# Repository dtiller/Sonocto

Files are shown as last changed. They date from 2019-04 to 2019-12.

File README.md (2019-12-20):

# Sonocto

This repo contains the MPLAB PIC code, Kicad board definition, and Arduino library and test suite for the Sonocto(tm) eight channel sonar module controller.

The author(s) assume/s no liability for your use of this code and no warranty, express or implied, exists.

The latest version is in the SonoctoPlus directory and uses a '1525 PIC. The code in the non-Plus directory is written for a '1523 PIC and may not have all of the features of the Plus version.

See the main.h and main.c files for details of the I2C protocol.

There are examples and test cases in the arduino area.

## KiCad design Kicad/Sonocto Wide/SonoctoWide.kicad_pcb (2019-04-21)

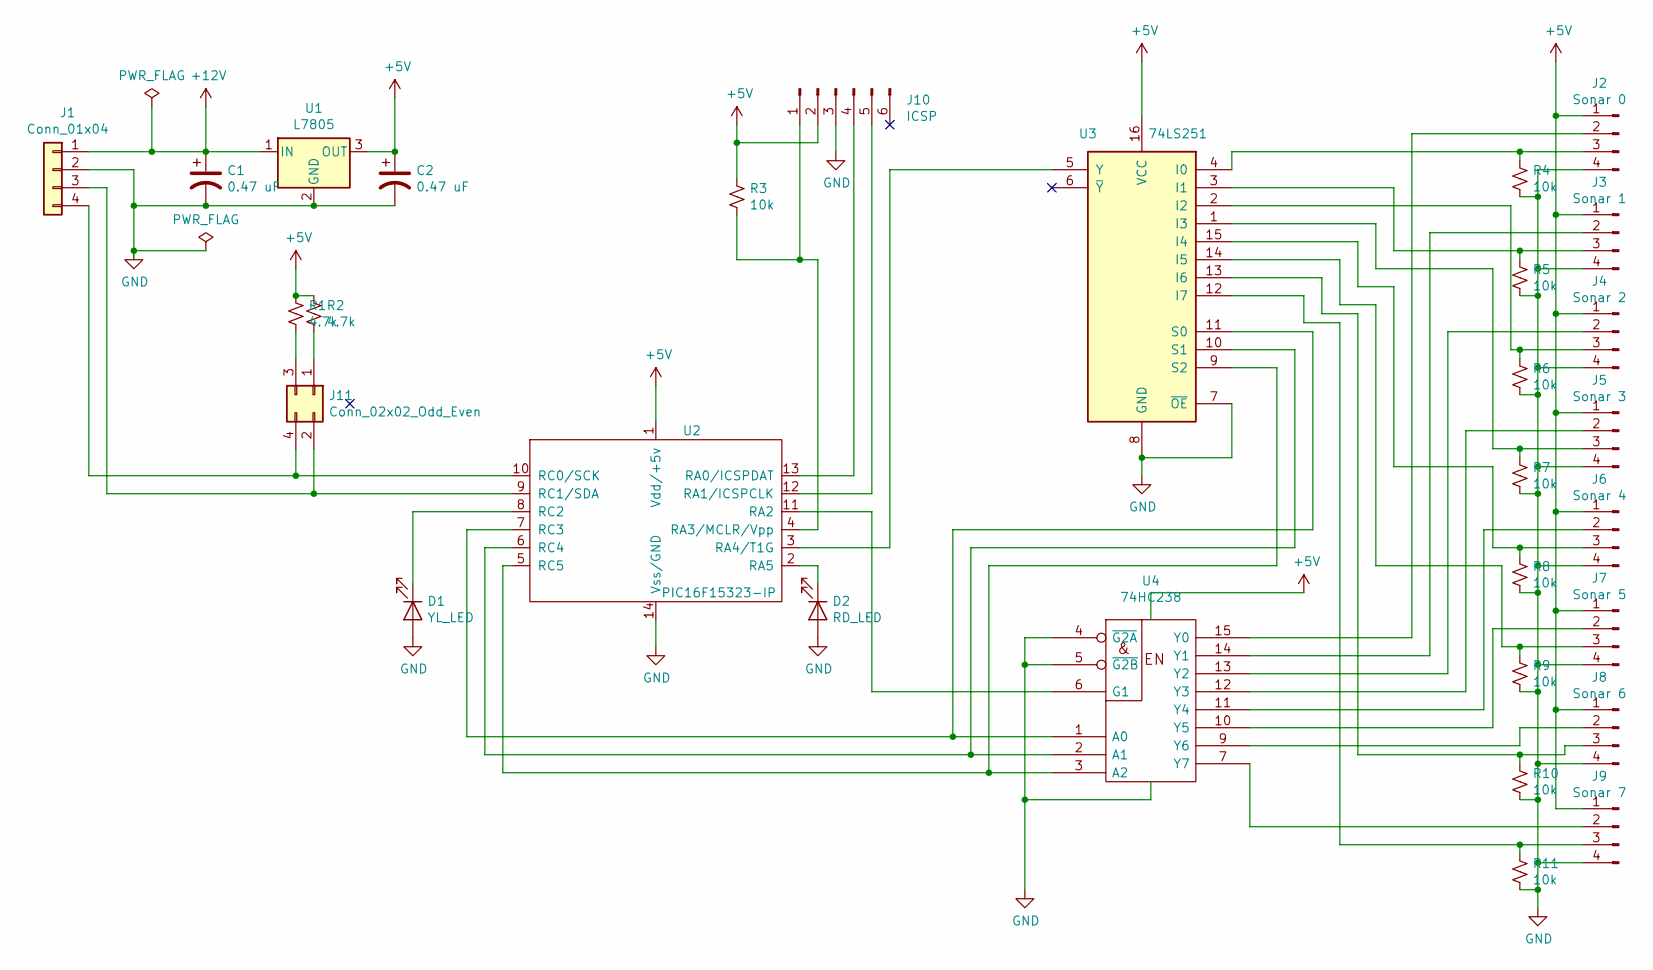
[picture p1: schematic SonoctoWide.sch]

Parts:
C1, C2: 0.47 uF; CP_Radial_D5.0mm_P2.00mm
D1: YL_LED; LED_D3.0mm
D2: RD_LED; LED_D3.0mm
J1: Conn_01x04; PinHeader_1x04_P2.54mm_Vertical
J2: Sonar 0; PinHeader_1x04_P2.54mm_Vertical
J3: Sonar 1; PinHeader_1x04_P2.54mm_Vertical
J4: Sonar 2; PinHeader_1x04_P2.54mm_Vertical
J5: Sonar 3; PinHeader_1x04_P2.54mm_Vertical
J6: Sonar 4; PinHeader_1x04_P2.54mm_Vertical
J7: Sonar 5; PinHeader_1x04_P2.54mm_Vertical
J8: Sonar 6; PinHeader_1x04_P2.54mm_Vertical
J9: Sonar 7; PinHeader_1x04_P2.54mm_Vertical
J10: ICSP; PinHeader_1x06_P2.54mm_Vertical
J11: Conn_02x02_Odd_Even; PinHeader_2x02_P2.54mm_Vertical
R1, R2: 4.7k; R_Axial_DIN0204_L3.6mm_D1.6mm_P1.90mm_Vertical
R3, R4, R5, R6, R7, R8, R9, R10, R11: 10k; R_Axial_DIN0204_L3.6mm_D1.6mm_P1.90mm_Vertical
U1: L7805; TO-220-3_Vertical
U2: PIC16F15323-IP; DIP-14_W7.62mm
U3: 74LS251; DIP-16_W7.62mm
U4: 74HC238; DIP-16_W7.62mm

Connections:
+5V: C2.1, J2.1, J3.1, J4.1, J5.1, J6.1, J7.1, J8.1, J9.1, J10.2, R1.1, R2.1, R3.1, U1.3 (OUT), U2.1 (Vdd/+5v), U3.16 (VCC), U4.16 (VCC)
+12V: C1.1, J1.1, U1.1 (IN)
GND: C1.2, C2.2, D1.2 (A), D2.2 (A), J1.2, J2.4, J3.4, J4.4, J5.4, J6.4, J7.4, J8.4, J9.4, J10.3, R4.2, R5.2, R6.2, R7.2, R8.2, R9.2, R10.2, R11.2, U1.2 (GND), U2.14 (Vss/GND), U3.7 (~OE), U3.8 (GND), U4.4 (~G2A), U4.5 (~G2B), U4.8 (GND)
unnamed: D1.1 (K), U2.8 (RC2)
unnamed: D2.1 (K), U2.2 (RA5)
unnamed: J1.3, J11.2, U2.9 (RC1/SDA)
unnamed: J1.4, J11.4, U2.10 (RC0/SCK)
unnamed: J2.2, U4.15 (Y0)
unnamed: J2.3, R4.1, U3.4 (I0)
unnamed: J3.2, U4.14 (Y1)
unnamed: J3.3, R5.1, U3.3 (I1)
unnamed: J4.2, U4.13 (Y2)
unnamed: J4.3, R6.1, U3.2 (I2)
unnamed: J5.2, U4.12 (Y3)
unnamed: J5.3, R7.1, U3.1 (I3)
unnamed: J6.2, U4.11 (Y4)
unnamed: J6.3, R8.1, U3.15 (I4)
unnamed: J7.2, U4.10 (Y5)
unnamed: J7.3, R9.1, U3.14 (I5)
unnamed: J8.2, U4.9 (Y6)
unnamed: J8.3, R10.1, U3.13 (I6)
unnamed: J9.2, U4.7 (Y7)
unnamed: J9.3, R11.1, U3.12 (I7)
unnamed: J10.1, R3.2, U2.4 (RA3/MCLR/Vpp)
unnamed: J10.4, U2.13 (RA0/ICSPDAT)
unnamed: J10.5, U2.12 (RA1/ICSPCLK)
unnamed: J11.1, R2.2
unnamed: J11.3, R1.2
unnamed: U2.3 (RA4/T1G), U3.5 (Y)
unnamed: U2.5 (RC5), U3.9 (S2), U4.3 (A2)
unnamed: U2.6 (RC4), U3.10 (S1), U4.2 (A1)
unnamed: U2.7 (RC3), U3.11 (S0), U4.1 (A0)
unnamed: U2.11 (RA2), U4.6 (G1)

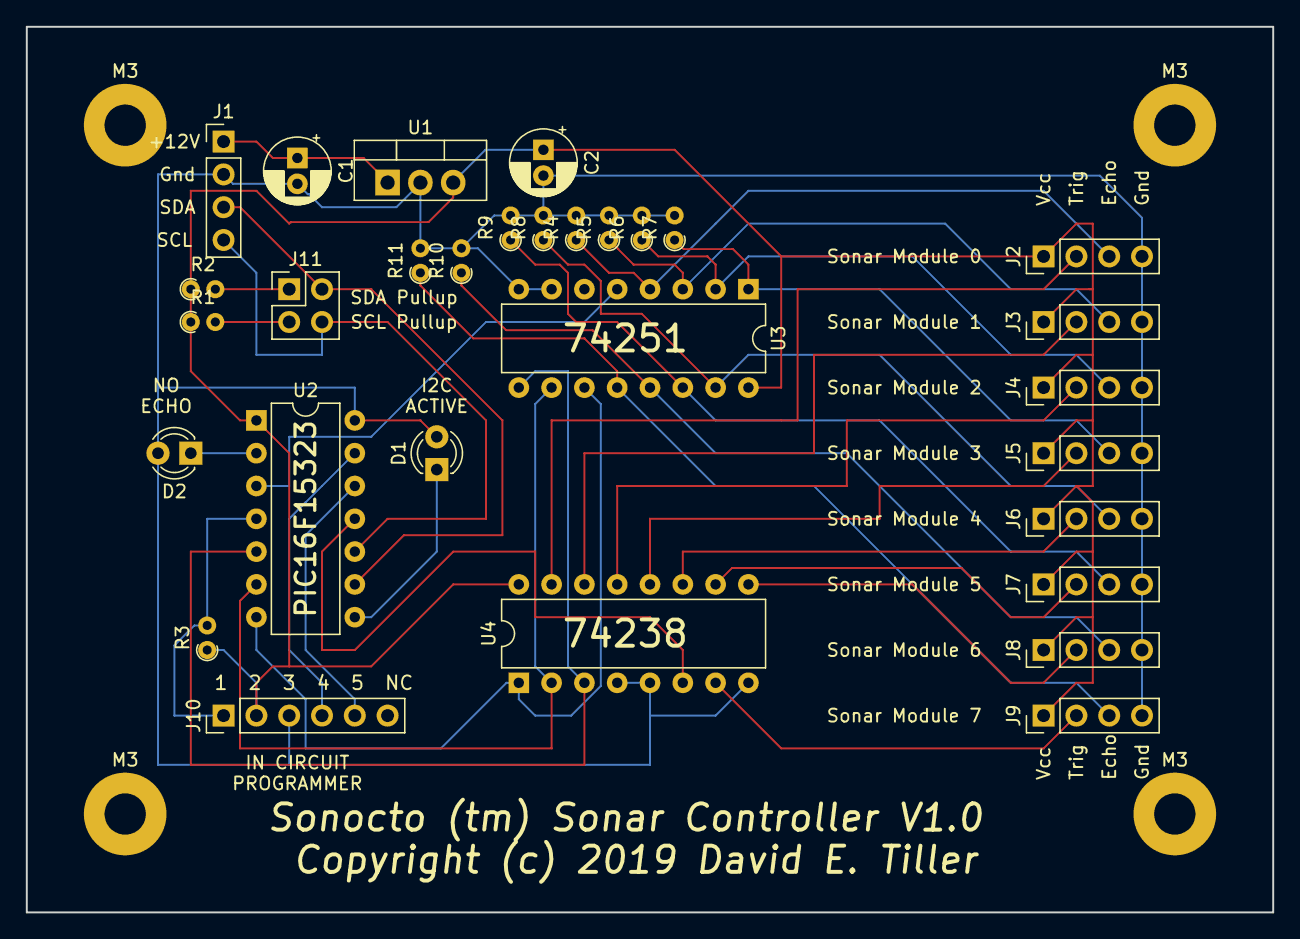
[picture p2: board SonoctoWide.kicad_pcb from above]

Board: 2 copper layers, 96.5 x 68.6 mm, 34 parts (0 on the bottom side), 33 nets.

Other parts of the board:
M3, M3#2, M3#3, M3#4: MountingHole_3.2mm_M3_Pad

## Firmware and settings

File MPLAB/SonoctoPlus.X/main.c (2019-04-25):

/**
  Generated Main Source File

  Company:
    Microchip Technology Inc.

  File Name:
    main.c

  Summary:
    This is the main file generated using PIC10 / PIC12 / PIC16 / PIC18 MCUs

  Description:
    This header file provides implementations for driver APIs for all modules selected in the GUI.
    Generation Information :
        Product Revision  :  PIC10 / PIC12 / PIC16 / PIC18 MCUs - 1.76
        Device            :  PIC16F15325
        Driver Version    :  2.00
*/

/*
    (c) 2018 Microchip Technology Inc. and its subsidiaries. 
    
    Subject to your compliance with these terms, you may use Microchip software and any 
    derivatives exclusively with Microchip products. It is your responsibility to comply with third party 
    license terms applicable to your use of third party software (including open source software) that 
    may accompany Microchip software.
    
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
    IN NO EVENT WILL MICROCHIP BE LIABLE FOR ANY INDIRECT, SPECIAL, PUNITIVE, 
    INCIDENTAL OR CONSEQUENTIAL LOSS, DAMAGE, COST OR EXPENSE OF ANY KIND 
    WHATSOEVER RELATED TO THE SOFTWARE, HOWEVER CAUSED, EVEN IF MICROCHIP 
    HAS BEEN ADVISED OF THE POSSIBILITY OR THE DAMAGES ARE FORESEEABLE. TO 
    THE FULLEST EXTENT ALLOWED BY LAW, MICROCHIP'S TOTAL LIABILITY ON ALL 
    CLAIMS IN ANY WAY RELATED TO THIS SOFTWARE WILL NOT EXCEED THE AMOUNT 
    OF FEES, IF ANY, THAT YOU HAVE PAID DIRECTLY TO MICROCHIP FOR THIS 
    SOFTWARE.
*/

#include "mcc_generated_files/mcc.h"
#include "mcc_generated_files/drivers/i2c_slave.h"

#include "main.h"

volatile uint16_t timerValue = 0;
volatile uint8_t count = 0;
volatile uint8_t waitForGate[8] = {0, 0, 0, 0, 0, 0, 0, 0};

volatile uint16_t maxReading[8] = {0, 0, 0, 0, 0, 0, 0, 0};
volatile uint16_t minReading[8] = {0xffff, 0xffff, 0xffff, 0xffff, 0xffff, 0xffff, 0xffff, 0xffff};

const uint16_t SAF_ADDR = END_FLASH - CONFIG_SIZE;

config_t config;

void initializeConfig(config_t *cfg) {
    cfg->cfg.i2cAddr = I2C_UPPER_BITS;
    cfg->cfg.enabled = 0xff;
    for (uint8_t i = 0; i < 8; i++) {
        cfg->cfg.maxEchoLimit[i] = 0x0f;
    }
}

uint8_t writeNVRAM(config_t *cfg) {
    return FLASH_WriteBlock(SAF_ADDR, cfg->dummy);
}

void readNVRAM(void) {
    uint16_t temp = FLASH_ReadWord(SAF_ADDR);
    if ((temp & 0x3f00) != 0) {
        // NVRAM not initialized - let's write the defaults in.
        writeNVRAM(&config);
    } else {
        for (uint8_t i = 0; i < WRITE_FLASH_BLOCKSIZE; i++) {
            config.dummy[i] = FLASH_ReadWord(SAF_ADDR + i);
        }
    }
}

// Read from the perspective of the SLAVE
void mySlaveReadHandler(void) {
    count = 0;
    LED_READ_SetHigh();
    
    uint8_t dataByte = i2c1_driver_getRXData();
    uint8_t channel = (dataByte & 0x07);
    uint8_t command;
    if (dataByte & 0x80) {
        command = CMD_ECHO_LIM_WRITE;
    } else if ((dataByte & 0xf0) == 0) {
        // 5 bit command + channel
        command = (dataByte >> 3) & 0x01;
    } else if ((dataByte & 0xf0) == 0x10) {
        command = ((dataByte >> 2) & 0x03) + 2;
    } else {
        command = ((dataByte >> 5) & 0x03) + 5;
    }
    
    switch (command) {
        case CMD_READ_DISTANCE:
            readDistance(channel);
            break;
        case CMD_READ_ECHOLIMIT:
            readEchoLimit(channel, dataByte);
            break;
        case CMD_MIN_MAX:
            readResetMinMaxStats(channel, dataByte);
            break;
        case CMD_ENABLE:
            enableDisable(channel, dataByte);
            break;
        case CMD_CONFIG:
            manageConfig(channel, dataByte);
            break;
        case CMD_ECHO_LIM_WRITE:
            setEchoLimit(channel, dataByte);
            break;
        case CMD_I2C_ADDR:
            setI2CAddr(channel, dataByte);
            break;
        case CMD_RESET:
            reboot(channel, dataByte);
            break;
        case CMD_VERSION:
            readVersion(channel, dataByte);
            break;
        case CMD_UNDEF_05:
        default:
            timerValue = UNKNOWN_CMD;
            break;          
    }
}

// [ 0 0 0 0 0 ] [ A A A ]
void readDistance(uint8_t channel) {
    // Set Up mux/demux
    //LATC = (LATC & 0xc7) | value;
    if ((config.cfg.enabled & (1 << channel)) == 0) {
        timerValue = CHANNEL_DISABLED;
        return;
    }
    
    LATCbits.LATC3 = channel & 0x01;
    LATCbits.LATC4 = (channel >> 1) & 0x01;
    LATCbits.LATC5 = (channel >> 2) & 0x01;
    
    if (waitForGate[channel]) {
        TMR0_WriteTimer(0x0000);
        TMR0_StartTimer();
        while (!TMR0_HasOverflowOccured() && TMR1_CheckGateValueStatus()) ;
        TMR0_StopTimer();
        if (TMR0_HasOverflowOccured()) {
            timerValue = GATE_TIMEOUT;
            PIR0bits.TMR0IF = 0;
            
            return;
        }
    }
    
    TMR1_WriteTimer(0x0000);
    TMR0_WriteTimer(0xFFFF - ((config.cfg.maxEchoLimit[channel] + 1) << 10) + 1);
    TMR0_StartTimer();
    TMR1_StartTimer();
    TMR1_StartSinglePulseAcquisition();
    
    TRIGGER_SetHigh();
    __delay_us(10);
    TRIGGER_SetLow();
    
    while (!TMR1_HasOverflowOccured() && !TMR0_HasOverflowOccured() &&
            T1GCONbits.GGO_nDONE == 1) ;
    
    TMR0_StopTimer();
    TMR1_StopTimer();
    
    waitForGate[channel] = 0;
    
    uint16_t t = TMR1_ReadTimer();
    if (TMR0_HasOverflowOccured()) {
        if (t == 0) {
            timerValue = NO_MODULE;
        } else {
            timerValue = NO_ECHO;
            waitForGate[channel] = 1;
            LED_OVFL_SetHigh();
        }
    } else if (TMR1_HasOverflowOccured()) {
        timerValue = TMR1_OVFL;
        waitForGate[channel] = 1;
        LED_OVFL_SetHigh();
    } else {
        timerValue = t;
        if (t > maxReading[channel]) maxReading[channel] = t;
        if (t < minReading[channel]) minReading[channel] = t;
        
        LED_OVFL_SetLow();
    }
    
    PIR0bits.TMR0IF = 0;
    PIR4bits.TMR1IF = 0;
}

// [ 0 0 0 0 1 ] [ A A A ]
void readEchoLimit(uint8_t channel, uint8_t dataByte) {
    timerValue = config.cfg.maxEchoLimit[channel];
}

// [ 0 0 1 ] [ 0 = min 1 = max ] [ = 0 read 1 = reset] [ A A A ]
void readResetMinMaxStats(uint8_t channel, uint8_t dataByte) {
    uint8_t max = dataByte & 0x10;
    if (dataByte & 0x08) {
        timerValue = 0;
        // RESET
        if (max) {
            maxReading[channel] = 0;
        } else {
            minReading[channel] = 0xffff;
        }
    } else {
        if (max) {
            timerValue = maxReading[channel];
        } else {
            timerValue = minReading[channel];
        }
    }
}

// [ 0 1 0 ] [ 0 = disable 1 = enable] [ 0 = read 1 = write ] [ A A A ]
void enableDisable(uint8_t channel, uint8_t dataByte) {
    // Always return the previous value
    timerValue = (config.cfg.enabled >> channel) & 0x01;
    if (dataByte & 0x08) {
        config.cfg.enabled &= ~(1 << channel);
        config.cfg.enabled |= ((dataByte >> 4) & 0x01) << channel;
    }
}

// [ 0 0 0 1 0 0 ] [ X Y ]
// X Y Action
// 0 0 Copy NVRAM --> current config
// 0 1 Set NVRAM config to default values
// 1 0 Set current config to default values
// 1 1 Copy current config to NVRAM
void manageConfig(uint8_t channel, uint8_t dataByte) {
    uint8_t action = dataByte & 0x03;
    timerValue = 0;
    switch (action) {
        case 0:
            readNVRAM();
            break;
        case 1:
        { config_t localConfig;
            initializeConfig(&localConfig);
            writeNVRAM(&localConfig);
            break;
        }
        case 2:
            initializeConfig(&config);
            break;
        case 3:
            writeNVRAM(&config);
            break;
    }
}

// [ 0 0 0 1 0 1 x x ]
// Reboot device
void reboot(uint8_t channel, uint8_t dataByte) {
    RESET();
}

// [ 0 0 0 1 1 0 x x ]
// Read Version
void readVersion(uint8_t channel, uint8_t dataByte) {
    timerValue = VERSION;
}

// [ 0 1 1 b4 b3 b2 b1 b0 ]
// Set I2C address to 0 1 b4 b3 b2 b1 b0 
void setI2CAddr(uint8_t channel, uint8_t dataByte) {
    timerValue = i2c1_driver_getAddr() >> 1;
    config.cfg.i2cAddr = I2C_UPPER_BITS | (dataByte & 0x1f);
    i2c1_driver_setAddr(config.cfg.i2cAddr << 1);
}

// [ 1 ] [ X X X X ] [ A A A ]
void setEchoLimit(uint8_t channel, uint8_t dataByte) {
    uint8_t limit = (dataByte >> 3) & 0x0f;
    timerValue = config.cfg.maxEchoLimit[channel];
    config.cfg.maxEchoLimit[channel] = limit;
}

// Write from the perspective of the SLAVE
void mySlaveWriteHandler(void) {
    //if (i2c1_driver_isNACK() == 1) return;
    if (i2c1_driver_isData() == 1 && i2c1_driver_isNACK() == 1) return;
    
    switch (count) {
        case 0:
            i2c1_driver_TXData((timerValue >> 8) & 0xff);
            count++;
            break;
        case 1:
            i2c1_driver_TXData(timerValue & 0xff);
            count++;
            LED_READ_SetLow();
            break;
        default:
            i2c1_driver_TXData(READ_INDEX_EXCEEDED);
            break;
    }       
}

void startupLights(void) {
    // Blink at the same time if WDT fired, alternately if not
    // Check for WDT reset
    
    LED_READ_SetLow();

    if (__timeout == 0) {
        LED_OVFL_SetLow();
    } else {
        LED_OVFL_SetHigh();
    }
    
    TMR0_WriteTimer(0x0000);
    TMR0_StartTimer();
    
    for (int i = 0; i < 10; i++) {
        while (!TMR0_HasOverflowOccured()) ;
        PIR0bits.TMR0IF = 0;
        LED_OVFL_Toggle();
        LED_READ_Toggle();
    }
    
    TMR0_StopTimer();
    LED_OVFL_SetLow();
    LED_READ_SetLow();
}

/*
                         Main application
 */
void main(void)
{   
    // initialize the device
    SYSTEM_Initialize();
    
    startupLights();
    
    initializeConfig(&config);
    
    readNVRAM();
    
    i2c_slave_open();
    i2c_slave_setWriteIntHandler(mySlaveWriteHandler);
    i2c_slave_setReadIntHandler(mySlaveReadHandler);
    i2c1_driver_setAddr(config.cfg.i2cAddr << 1);
    i2c1_driver_start();    // Sets SEN = 1
    mssp1_enableIRQ();      // Sets SSP1IE = 1
    
    // When using interrupts, you need to set the Global and Peripheral Interrupt Enable bits
    // Use the following macros to:
    // Enable the Global Interrupts
    INTERRUPT_GlobalInterruptEnable();

    // Enable the Peripheral Interrupts
    INTERRUPT_PeripheralInterruptEnable();

    // Disable the Global Interrupts
    //INTERRUPT_GlobalInterruptDisable();

    // Disable the Peripheral Interrupts
    //INTERRUPT_PeripheralInterruptDisable();
      
    while (1)
    {
        CLRWDT();
    }
}
/**
 End of File
*/

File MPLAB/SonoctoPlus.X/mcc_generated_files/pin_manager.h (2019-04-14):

/**
  @Generated Pin Manager Header File

  @Company:
    Microchip Technology Inc.

  @File Name:
    pin_manager.h

  @Summary:
    This is the Pin Manager file generated using PIC10 / PIC12 / PIC16 / PIC18 MCUs

  @Description
    This header file provides APIs for driver for .
    Generation Information :
        Product Revision  :  PIC10 / PIC12 / PIC16 / PIC18 MCUs - 1.76
        Device            :  PIC16F15325
        Driver Version    :  2.11
    The generated drivers are tested against the following:
        Compiler          :  XC8 2.00
        MPLAB 	          :  MPLAB X 5.10	
*/

/*
    (c) 2018 Microchip Technology Inc. and its subsidiaries. 
    
    Subject to your compliance with these terms, you may use Microchip software and any 
    derivatives exclusively with Microchip products. It is your responsibility to comply with third party 
    license terms applicable to your use of third party software (including open source software) that 
    may accompany Microchip software.
    
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
    IN NO EVENT WILL MICROCHIP BE LIABLE FOR ANY INDIRECT, SPECIAL, PUNITIVE, 
    INCIDENTAL OR CONSEQUENTIAL LOSS, DAMAGE, COST OR EXPENSE OF ANY KIND 
    WHATSOEVER RELATED TO THE SOFTWARE, HOWEVER CAUSED, EVEN IF MICROCHIP 
    HAS BEEN ADVISED OF THE POSSIBILITY OR THE DAMAGES ARE FORESEEABLE. TO 
    THE FULLEST EXTENT ALLOWED BY LAW, MICROCHIP'S TOTAL LIABILITY ON ALL 
    CLAIMS IN ANY WAY RELATED TO THIS SOFTWARE WILL NOT EXCEED THE AMOUNT 
    OF FEES, IF ANY, THAT YOU HAVE PAID DIRECTLY TO MICROCHIP FOR THIS 
    SOFTWARE.
*/

#ifndef PIN_MANAGER_H
#define PIN_MANAGER_H

/**
  Section: Included Files
*/

#include <xc.h>

#define INPUT   1
#define OUTPUT  0

#define HIGH    1
#define LOW     0

#define ANALOG      1
#define DIGITAL     0

#define PULL_UP_ENABLED      1
#define PULL_UP_DISABLED     0

// get/set TRIGGER aliases
#define TRIGGER_TRIS                 TRISAbits.TRISA2
#define TRIGGER_LAT                  LATAbits.LATA2
#define TRIGGER_PORT                 PORTAbits.RA2
#define TRIGGER_WPU                  WPUAbits.WPUA2
#define TRIGGER_OD                   ODCONAbits.ODCA2
#define TRIGGER_ANS                  ANSELAbits.ANSA2
#define TRIGGER_SetHigh()            do { LATAbits.LATA2 = 1; } while(0)
#define TRIGGER_SetLow()             do { LATAbits.LATA2 = 0; } while(0)
#define TRIGGER_Toggle()             do { LATAbits.LATA2 = ~LATAbits.LATA2; } while(0)
#define TRIGGER_GetValue()           PORTAbits.RA2
#define TRIGGER_SetDigitalInput()    do { TRISAbits.TRISA2 = 1; } while(0)
#define TRIGGER_SetDigitalOutput()   do { TRISAbits.TRISA2 = 0; } while(0)
#define TRIGGER_SetPullup()          do { WPUAbits.WPUA2 = 1; } while(0)
#define TRIGGER_ResetPullup()        do { WPUAbits.WPUA2 = 0; } while(0)
#define TRIGGER_SetPushPull()        do { ODCONAbits.ODCA2 = 0; } while(0)
#define TRIGGER_SetOpenDrain()       do { ODCONAbits.ODCA2 = 1; } while(0)
#define TRIGGER_SetAnalogMode()      do { ANSELAbits.ANSA2 = 1; } while(0)
#define TRIGGER_SetDigitalMode()     do { ANSELAbits.ANSA2 = 0; } while(0)

// get/set RA4 procedures
#define RA4_SetHigh()            do { LATAbits.LATA4 = 1; } while(0)
#define RA4_SetLow()             do { LATAbits.LATA4 = 0; } while(0)
#define RA4_Toggle()             do { LATAbits.LATA4 = ~LATAbits.LATA4; } while(0)
#define RA4_GetValue()              PORTAbits.RA4
#define RA4_SetDigitalInput()    do { TRISAbits.TRISA4 = 1; } while(0)
#define RA4_SetDigitalOutput()   do { TRISAbits.TRISA4 = 0; } while(0)
#define RA4_SetPullup()             do { WPUAbits.WPUA4 = 1; } while(0)
#define RA4_ResetPullup()           do { WPUAbits.WPUA4 = 0; } while(0)
#define RA4_SetAnalogMode()         do { ANSELAbits.ANSA4 = 1; } while(0)
#define RA4_SetDigitalMode()        do { ANSELAbits.ANSA4 = 0; } while(0)

// get/set LED_OVFL aliases
#define LED_OVFL_TRIS                 TRISAbits.TRISA5
#define LED_OVFL_LAT                  LATAbits.LATA5
#define LED_OVFL_PORT                 PORTAbits.RA5
#define LED_OVFL_WPU                  WPUAbits.WPUA5
#define LED_OVFL_OD                   ODCONAbits.ODCA5
#define LED_OVFL_ANS                  ANSELAbits.ANSA5
#define LED_OVFL_SetHigh()            do { LATAbits.LATA5 = 1; } while(0)
#define LED_OVFL_SetLow()             do { LATAbits.LATA5 = 0; } while(0)
#define LED_OVFL_Toggle()             do { LATAbits.LATA5 = ~LATAbits.LATA5; } while(0)
#define LED_OVFL_GetValue()           PORTAbits.RA5
#define LED_OVFL_SetDigitalInput()    do { TRISAbits.TRISA5 = 1; } while(0)
#define LED_OVFL_SetDigitalOutput()   do { TRISAbits.TRISA5 = 0; } while(0)
#define LED_OVFL_SetPullup()          do { WPUAbits.WPUA5 = 1; } while(0)
#define LED_OVFL_ResetPullup()        do { WPUAbits.WPUA5 = 0; } while(0)
#define LED_OVFL_SetPushPull()        do { ODCONAbits.ODCA5 = 0; } while(0)
#define LED_OVFL_SetOpenDrain()       do { ODCONAbits.ODCA5 = 1; } while(0)
#define LED_OVFL_SetAnalogMode()      do { ANSELAbits.ANSA5 = 1; } while(0)
#define LED_OVFL_SetDigitalMode()     do { ANSELAbits.ANSA5 = 0; } while(0)

// get/set SCL1 aliases
#define SCL1_TRIS                 TRISCbits.TRISC0
#define SCL1_LAT                  LATCbits.LATC0
#define SCL1_PORT                 PORTCbits.RC0
#define SCL1_WPU                  WPUCbits.WPUC0
#define SCL1_OD                   ODCONCbits.ODCC0
#define SCL1_ANS                  ANSELCbits.ANSC0
#define SCL1_SetHigh()            do { LATCbits.LATC0 = 1; } while(0)
#define SCL1_SetLow()             do { LATCbits.LATC0 = 0; } while(0)
#define SCL1_Toggle()             do { LATCbits.LATC0 = ~LATCbits.LATC0; } while(0)
#define SCL1_GetValue()           PORTCbits.RC0
#define SCL1_SetDigitalInput()    do { TRISCbits.TRISC0 = 1; } while(0)
#define SCL1_SetDigitalOutput()   do { TRISCbits.TRISC0 = 0; } while(0)
#define SCL1_SetPullup()          do { WPUCbits.WPUC0 = 1; } while(0)
#define SCL1_ResetPullup()        do { WPUCbits.WPUC0 = 0; } while(0)
#define SCL1_SetPushPull()        do { ODCONCbits.ODCC0 = 0; } while(0)
#define SCL1_SetOpenDrain()       do { ODCONCbits.ODCC0 = 1; } while(0)
#define SCL1_SetAnalogMode()      do { ANSELCbits.ANSC0 = 1; } while(0)
#define SCL1_SetDigitalMode()     do { ANSELCbits.ANSC0 = 0; } while(0)
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

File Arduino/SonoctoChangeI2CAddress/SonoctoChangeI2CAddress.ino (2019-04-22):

#include "Sonocto.h"

#define OLD_ADDRESS DEFAULT_I2C_ADDR
#define NEW_ADDRESS 0x21
void setup() {
  Sonocto.begin(400000);
  Serial.begin(115200);

  Serial.print("Changing Sonocto i2c address from "); Serial.print(OLD_ADDRESS); 
  Serial.print(" to "); Serial.print(NEW_ADDRESS); Serial.println(" in 10 seconds");
  delay(10000);
  uint16_t value = Sonocto.setI2CAddr(OLD_ADDRESS, NEW_ADDRESS);
  if (value != OLD_ADDRESS) {
    Serial.print("Address change failed: "); Serial.println(value);
    return;
  }
  
  Serial.println("Address changed successfully - writing config to NVRAM.");
  value = Sonocto.writeConfigToNVRAM(NEW_ADDRESS);
  if (value != 0) {
    Serial.println("Write to NVRAM failed: "); Serial.println(value);
    return;
  }

  Serial.print("Rebooting....");
  Sonocto.reboot(NEW_ADDRESS);
  Serial.println("Done.");
 
}

void loop() {
  Serial.println("Complete. Power off the module.");
  delay(2000);

}

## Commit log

2019-04-14 Added remainder of files.
    [Preconmove.kicad_pcb, Sonocto SMT.kicad_pcb, Sonocto SMT.sch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]
2019-04-20 Added reboot and setI2CAddr commands.
    Moved config management command.
    Changed config EPROM layout - added i2c addr in there.
    Added test for reboot.
    Added copyArduino.sh script to copy over the files since Arduino doesn't like projects and
    libraries anywhere but under it's 'home' folder.
    TODO:
    Flesh out setting I2C addr on startup.
    Add test for setI2CAddr.
    [SonoctoTestSuite.ino, main.c]
2019-04-21 Added hole center-to-center dimension.
    [Sonocto.kicad_pcb, SonoctoWide.kicad_pcb]
2019-04-22 1) Added change I2C address logic. The valid address range is UPPER_I2C_BITS to UPPER_I2C_BITS + 0x1F (0x20-0x3F). 2) Created new Arduino sketch to change I2C addresses on boards. 3) Added just-in-ca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
2019-04-24 Added CHANNEL #define to test suite. Changed programmer to low voltage (again).

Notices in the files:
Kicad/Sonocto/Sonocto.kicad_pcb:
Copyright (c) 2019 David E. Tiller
